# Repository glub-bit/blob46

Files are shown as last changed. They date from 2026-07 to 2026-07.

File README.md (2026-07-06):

# blob46
This a reversable 100x100mm pcb split keyboard with a number row. Compatible with choc v2 switches and has a gasket mounted case.

# Bill of Materials

| Component | Quantity | Link | Price |
| --- | --- | ---- | ----- |
| SMD diodes 0805 | 46 | https://www.aliexpress.us/item/3256806974248533.html?spm= | $1.66 |
| RP2040 zero | 2 | https://www.aliexpress.us/item/3256808552177000.html?spm= | $4.78 |
| M2 5mm screws | 12 | https://www.aliexpress.us/item/2251832624557792.html?spm= | $1.41 |
| M2 heated inserts Length: 3mm OD: 4mm | 12 | https://www.aliexpress.us/item/3256803396040989.html?spm= | $1.69 |
| PJ-320A | 2 | https://www.aliexpress.us/item/3256805376463085.html?spm= | $1.21 |
| TRRS male to male cable | 2 | https://www.aliexpress.us/item/3256809654236904.html?spm= | $2.78 |
| Poron foam 3mm thickness | 24-28 | https://www.aliexpress.us/item/3256806077981729.html?spm=](https://www.aliexpress.us/item/3256803420779042.html?spm= | $2.24 |

*pricing may change

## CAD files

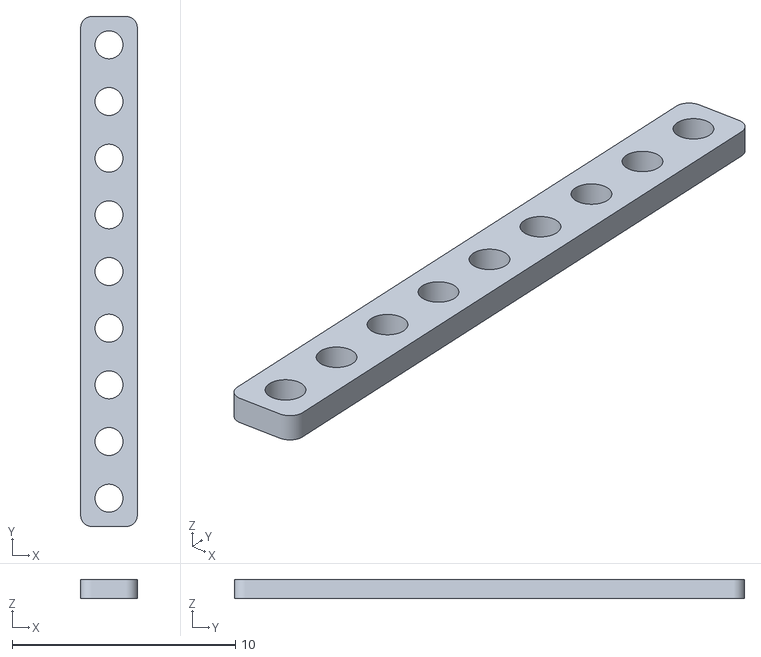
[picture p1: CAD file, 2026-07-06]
case and plate CAD/glob46 parts - rp2040 spacer.stl
2.54 x 22.9 x 0.86

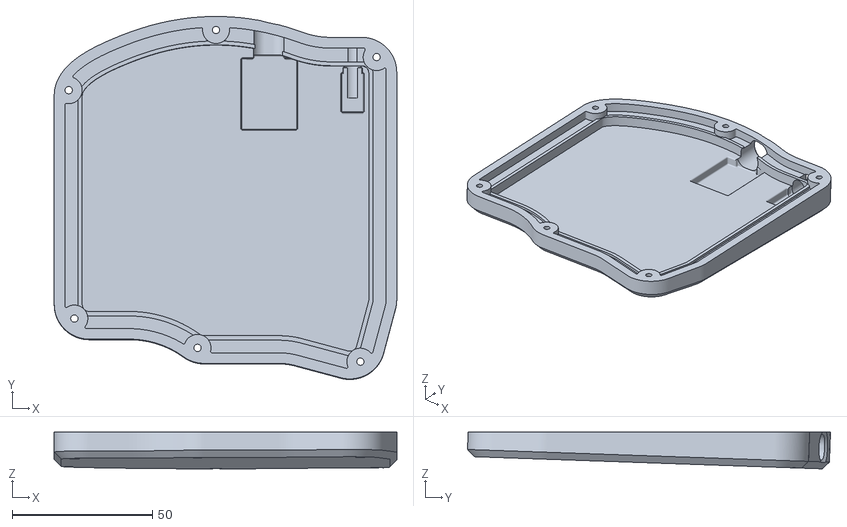
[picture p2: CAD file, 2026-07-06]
case and plate CAD/glob46 parts - case left bottom.stl
122.3 x 129.6 x 13.1

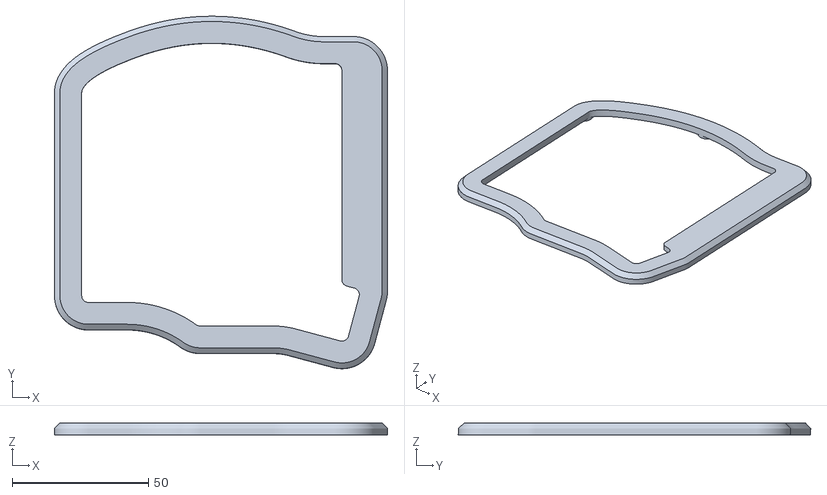
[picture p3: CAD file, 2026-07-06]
case and plate CAD/glob46 parts - case left top.stl
122.3 x 129.5 x 4.40

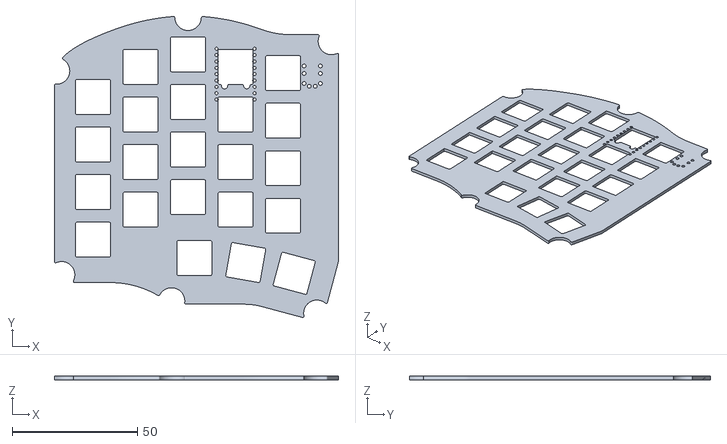
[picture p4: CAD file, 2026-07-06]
case and plate CAD/glob46 parts - plate.stl
113.7 x 120.4 x 1.40

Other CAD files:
case and plate CAD/glob46 parts - case right bottom.stl
case and plate CAD/glob46 parts - case right top.stl

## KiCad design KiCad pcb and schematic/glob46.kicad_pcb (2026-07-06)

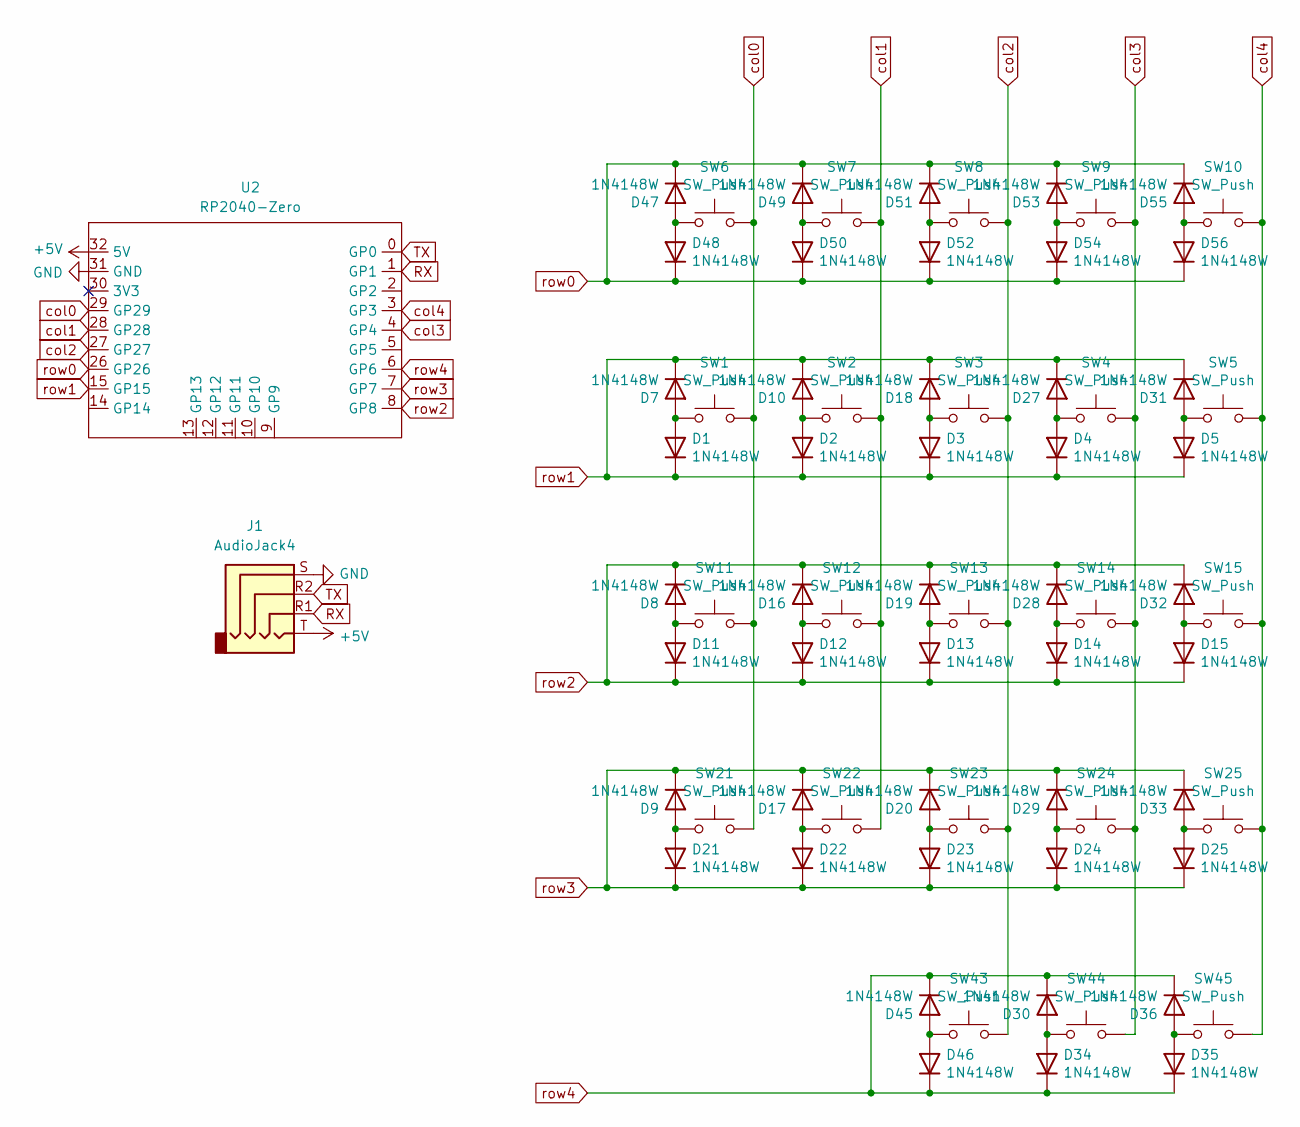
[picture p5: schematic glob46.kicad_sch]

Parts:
D1, D2, D3, D4, D5, D7, D8, D9, D10, D11, D12, D13, D14, D15, D16, D17, D18, D19, D20, D21, D22, D23, D24, D25, D27, D28, D29, D30, D31, D32, D33, D34, D35, D36, D45, D46, D47, D48, D49, D50, D51, D52, D53, D54, D55, D56: 1N4148W; D_SOD-123; LCSC C727110
J1: AudioJack4; CON_MJ-4PP-9_Reversible
SW1, SW2, SW3, SW4, SW5, SW6, SW7, SW8, SW9, SW10, SW11, SW12, SW13, SW14, SW15, SW21, SW22, SW23, SW24, SW25, SW43, SW44, SW45: SW_Push; SW_Kailh_Choc_V2_1.00u
U2: RP2040-Zero; MCU_RP2040_Zero_34

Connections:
+5V: J1.T, U2.32 (5V)
GND: J1.S, U2.31 (GND)
unnamed: D1.2 (A), D7.2 (A), SW1.1
unnamed: D2.2 (A), D10.2 (A), SW2.1
unnamed: D8.2 (A), D11.2 (A), SW11.1
unnamed: D12.2 (A), D16.2 (A), SW12.1
unnamed: D13.2 (A), D19.2 (A), SW13.1
unnamed: D14.2 (A), D28.2 (A), SW14.1
unnamed: D15.2 (A), D32.2 (A), SW15.1
unnamed: D17.2 (A), D22.2 (A), SW22.1
unnamed: D3.2 (A), D18.2 (A), SW3.1
unnamed: D20.2 (A), D23.2 (A), SW23.1
unnamed: D9.2 (A), D21.2 (A), SW21.1
unnamed: D24.2 (A), D29.2 (A), SW24.1
unnamed: D25.2 (A), D33.2 (A), SW25.1
unnamed: D4.2 (A), D27.2 (A), SW4.1
unnamed: D30.2 (A), D34.2 (A), SW44.1
unnamed: D5.2 (A), D31.2 (A), SW5.1
unnamed: D35.2 (A), D36.2 (A), SW45.1
unnamed: D45.2 (A), D46.2 (A), SW43.1
unnamed: D47.2 (A), D48.2 (A), SW6.1
unnamed: D49.2 (A), D50.2 (A), SW7.1
unnamed: D51.2 (A), D52.2 (A), SW8.1
unnamed: D53.2 (A), D54.2 (A), SW9.1
unnamed: D55.2 (A), D56.2 (A), SW10.1
RX: J1.R1, U2.1 (GP1)
TX: J1.R2, U2.0 (GP0)
col0: SW1.2, SW6.2, SW11.2, SW21.2, U2.29 (GP29)
col1: SW2.2, SW7.2, SW12.2, SW22.2, U2.28 (GP28)
col2: SW3.2, SW8.2, SW13.2, SW23.2, SW43.2, U2.27 (GP27)
col3: SW4.2, SW9.2, SW14.2, SW24.2, SW44.2, U2.4 (GP4)
col4: SW5.2, SW10.2, SW15.2, SW25.2, SW45.2, U2.3 (GP3)
row0: D47.1 (K), D48.1 (K), D49.1 (K), D50.1 (K), D51.1 (K), D52.1 (K), D53.1 (K), D54.1 (K), D55.1 (K), D56.1 (K), U2.26 (GP26)
row1: D1.1 (K), D2.1 (K), D3.1 (K), D4.1 (K), D5.1 (K), D7.1 (K), D10.1 (K), D18.1 (K), D27.1 (K), D31.1 (K), U2.15 (GP15)
row2: D8.1 (K), D11.1 (K), D12.1 (K), D13.1 (K), D14.1 (K), D15.1 (K), D16.1 (K), D19.1 (K), D28.1 (K), D32.1 (K), U2.8 (GP8)
row3: D9.1 (K), D17.1 (K), D20.1 (K), D21.1 (K), D22.1 (K), D23.1 (K), D24.1 (K), D25.1 (K), D29.1 (K), D33.1 (K), U2.7 (GP7)
row4: D30.1 (K), D34.1 (K), D35.1 (K), D36.1 (K), D45.1 (K), D46.1 (K), U2.6 (GP6)

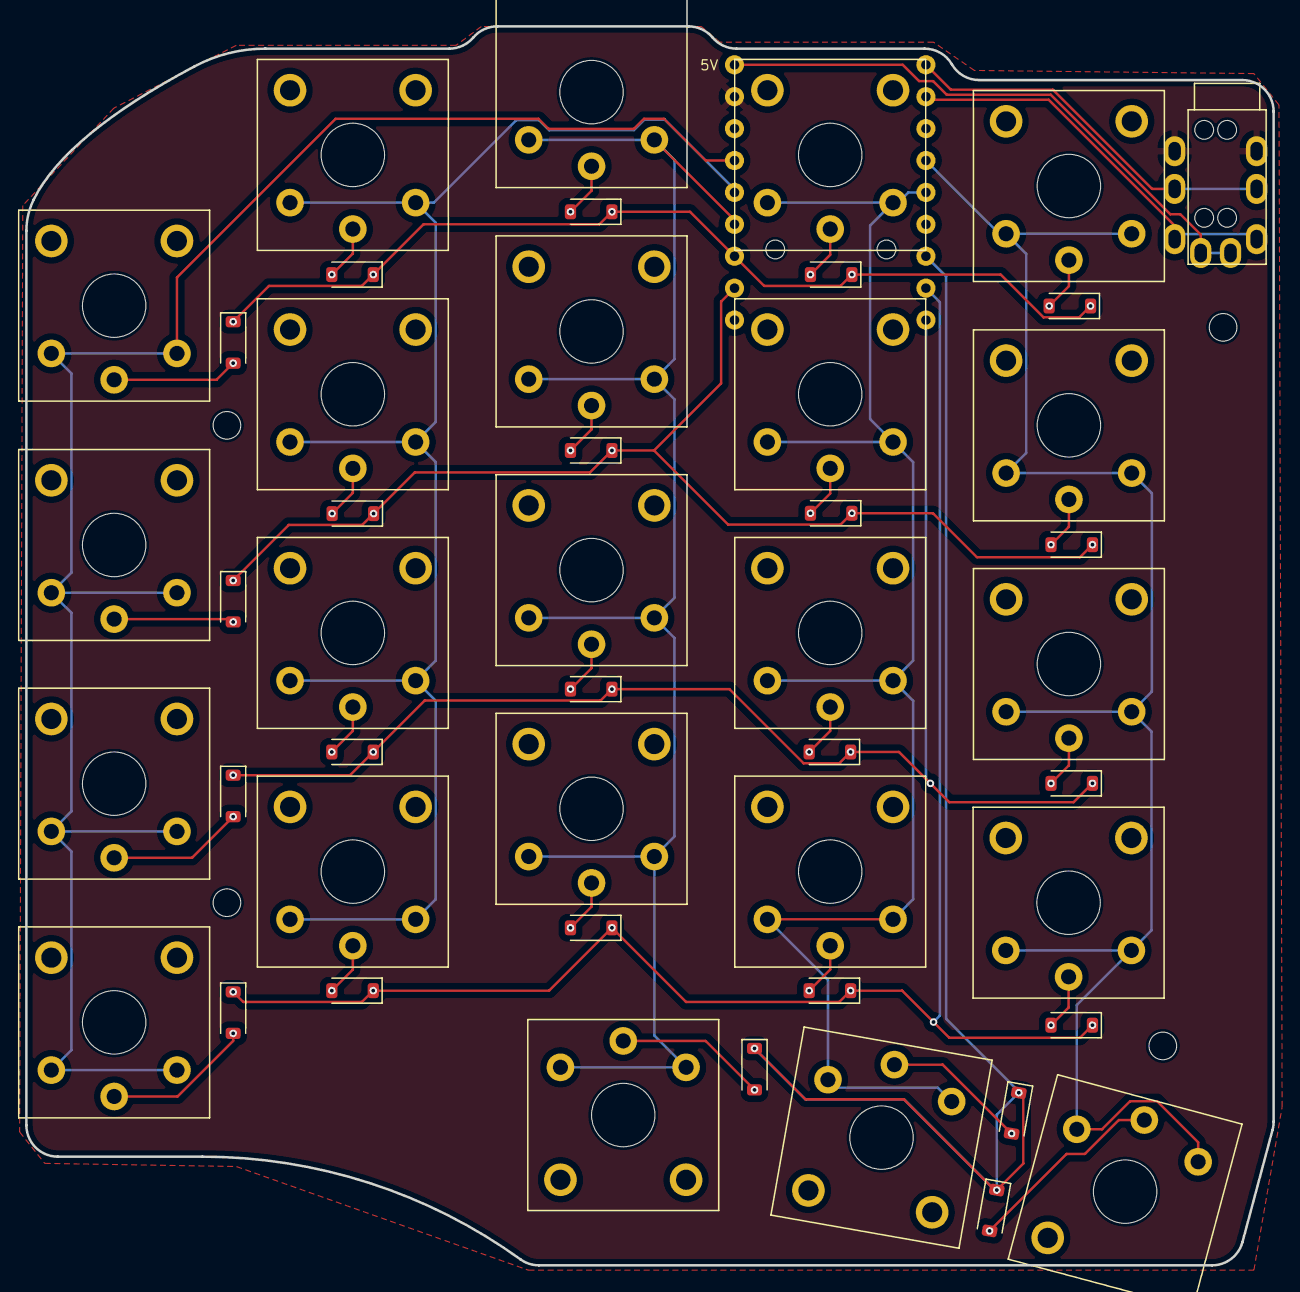
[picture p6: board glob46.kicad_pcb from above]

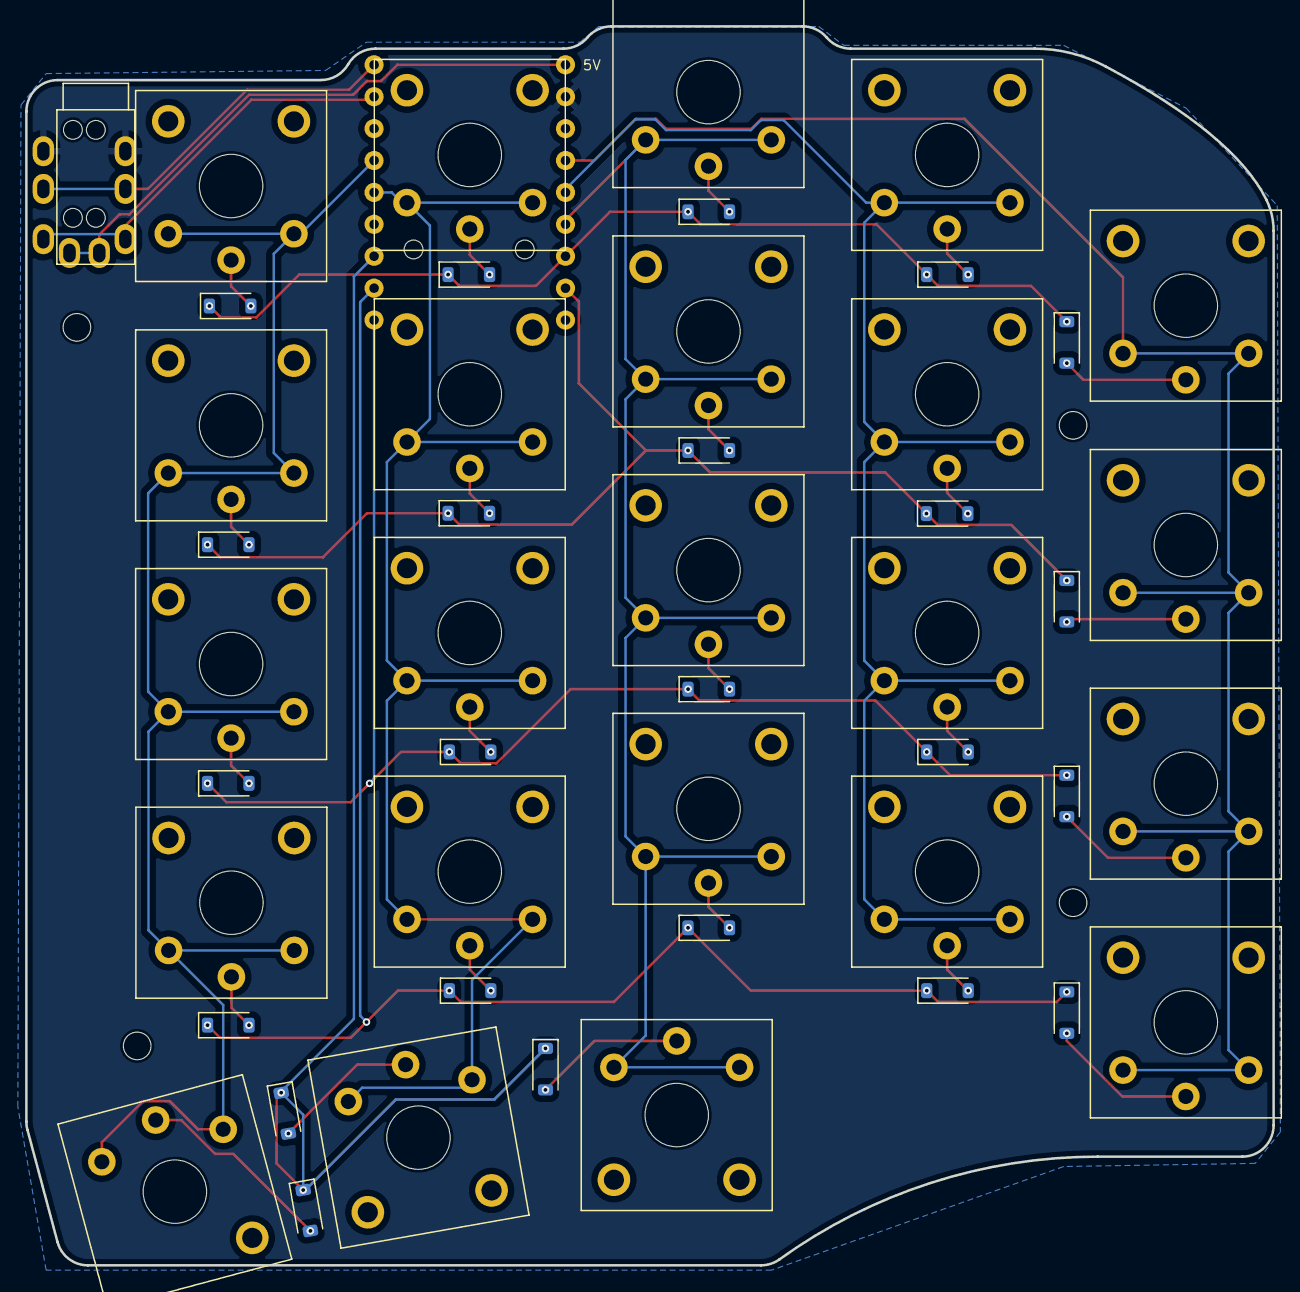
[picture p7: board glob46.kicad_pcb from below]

Board: 2 copper layers, 99.3 x 98.6 mm, 71 parts (23 on the bottom side), 37 nets.
